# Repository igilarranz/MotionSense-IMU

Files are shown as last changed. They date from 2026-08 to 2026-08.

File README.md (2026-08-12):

# MotionSense IMU

MotionSense IMU is a custom 2-layer PCB built around the ST LSM6DSM 6-axis accelerometer and gyroscope.

The board takes 5 V from USB-C, regulates it to 3.3 V, and breaks out the IMU's I2C interface and interrupt signal through a 5-pin header.

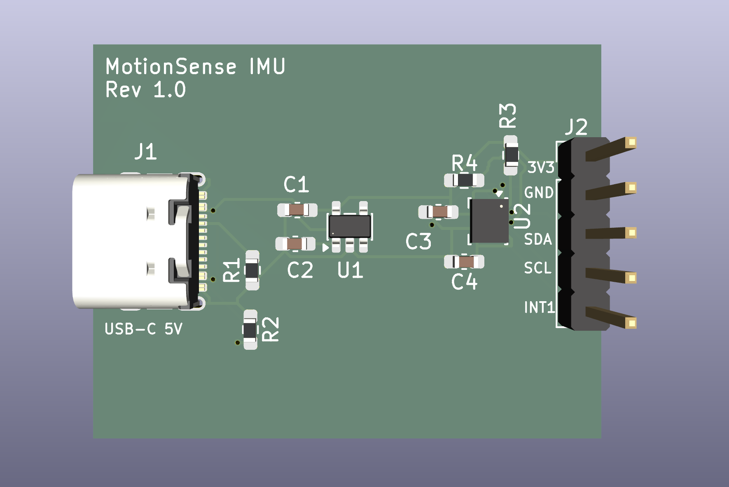
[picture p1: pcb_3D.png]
MotionSense IMU 3D Render


## Hardware

* LSM6DSM 6-axis accelerometer + gyroscope
* AP2112K-3.3 LDO regulator
* USB-C 5 V input
* 4.7 kΩ pull-up resistors on SDA and SCL
* Decoupling capacitors for the regulator and IMU
* 5-pin interface header
* 2-layer PCB
* Board size: approximately 35 mm × 27 mm

## Pinout

| Pin | Signal |
| --- | --- |
| 1 | 3V3 |
| 2 | GND |
| 3 | SDA |
| 4 | SCL |
| 5 | INT1 |

## Design

The schematic and PCB were designed in KiCad.

During routing, I experimented with Quilter and Freerouting before bringing the design back into KiCad for final cleanup and verification.

The final design passes KiCad DRC with:

* 0 violations
* 0 unconnected items

Gerber and drill files were generated and inspected before manufacturing.

## Schematic

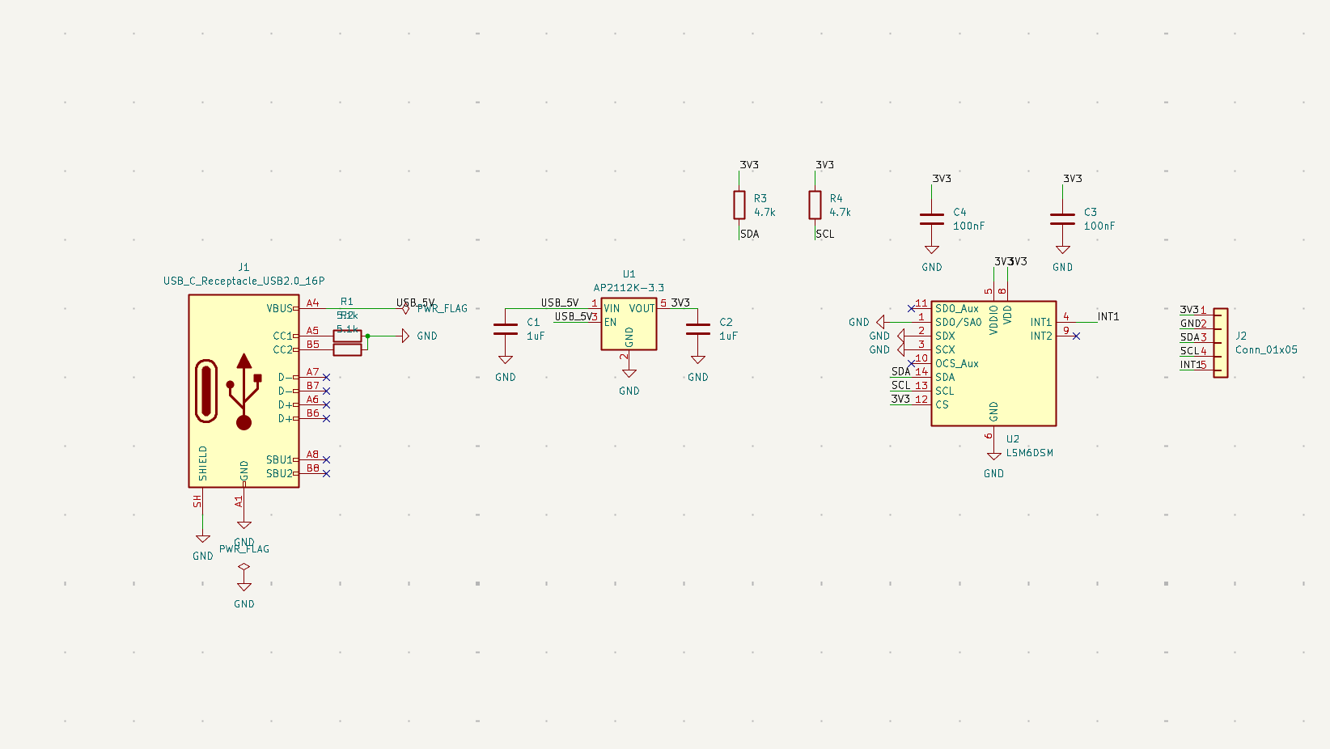
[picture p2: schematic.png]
MotionSense IMU Schematic


The schematic includes the USB-C power input, AP2112K 3.3 V regulator, LSM6DSM IMU, I2C pull-up resistors, decoupling capacitors, and J2 breakout header.

The editable KiCad schematic is available in `MotionSense_IMU.kicad_sch`.

## PCB Layout

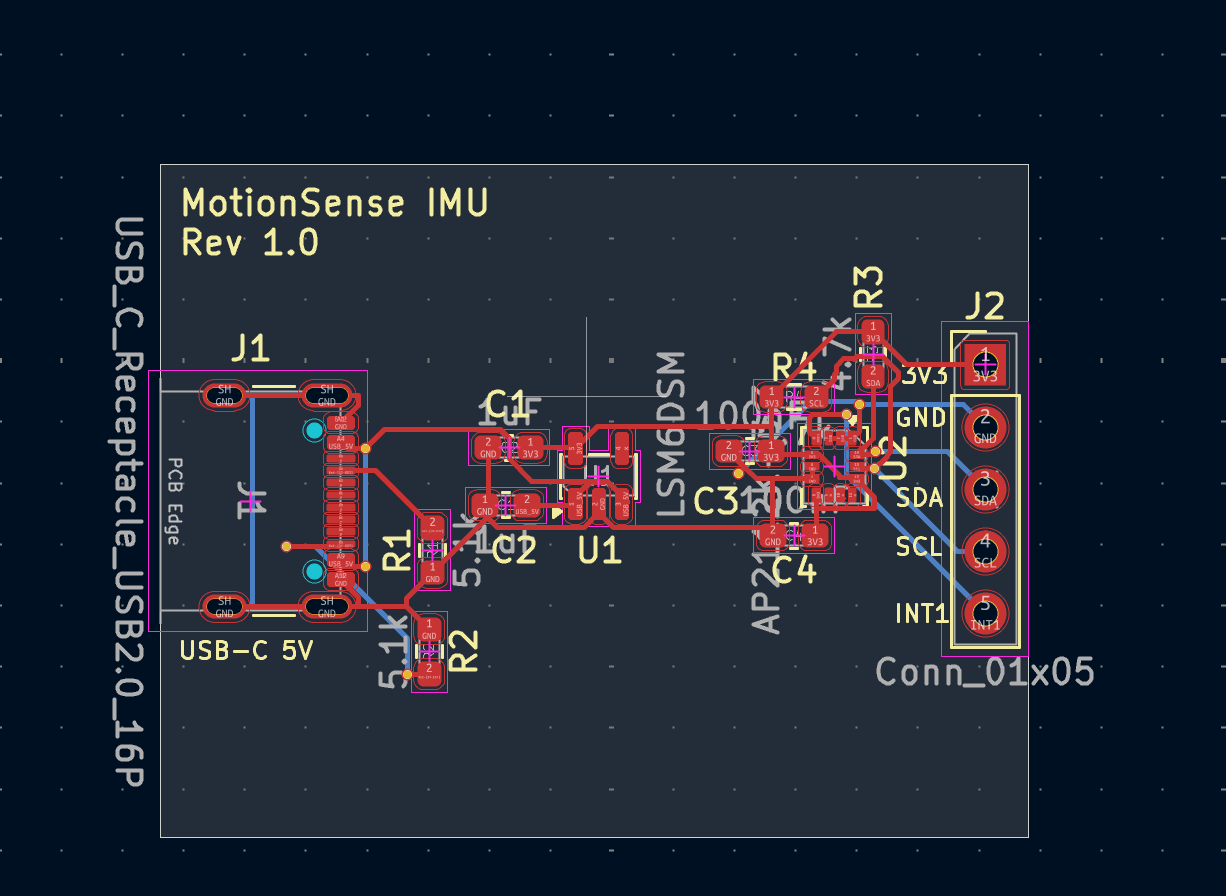
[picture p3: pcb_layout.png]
MotionSense IMU PCB Layout


The board is a 2-layer design with USB-C power input on one side and the I2C breakout header on the opposite side.

## Manufacturing

Rev 1 was submitted to JLCPCB for fabrication and assembly in August 2026.

Five PCBs were ordered, with two boards receiving component assembly.

The 1×5 J2 header is intentionally left unpopulated and will be soldered manually during bring-up.

## Files

* `MotionSense_IMU.kicad_pcb` — KiCad PCB layout
* `MotionSense_IMU.kicad_pro` — KiCad project
* `MotionSense_IMU.kicad_sch` — KiCad schematic
* `BOM.csv` — bill of materials
* `MotionSense_IMU_Rev1_Gerbers.zip` — Gerber and drill files
* `pcb_3D.png` — 3D board render
* `pcb_layout.png` — PCB layout image
* `schematic.png` — schematic image

## Fabrication Files

The Rev 1 Gerber and drill files used for manufacturing are included in the repository.

[Download Gerber + drill files](https://github.com/igilarranz/MotionSense-IMU/raw/refs/heads/main/MotionSense_IMU_Rev1_Gerbers.zip)

## Current Status

**Rev 1 has been ordered for fabrication and assembly.**

The PCB design and manufacturing files are complete. The next stage is hardware bring-up and firmware validation once the assembled boards arrive.

## Bring-Up Plan

1. Inspect the assembled board for soldering or placement issues.
2. Solder the J2 header.
3. Check for shorts between 3.3 V and GND.
4. Power the board through USB-C.
5. Verify the 5 V input and 3.3 V regulator output with a multimeter.
6. Connect an ESP32 to SDA, SCL, and GND.
7. Detect the LSM6DSM over I2C.
8. Read the `WHO_AM_I` register to confirm communication.
9. Read live accelerometer and gyroscope data.
10. Test the INT1 interrupt output.

## Next Steps

* Prepare ESP32 bring-up firmware
* Complete electrical testing
* Validate accelerometer and gyroscope measurements
* Test interrupt functionality
* Document test results
* Record any changes needed for Rev 2

## Project Goal

The goal of this project is to work through the complete PCB development process, from schematic capture and component selection through layout, manufacturing, assembly, and hardware validation.

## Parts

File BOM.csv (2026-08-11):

Reference | Value | Footprint
C1 | 1uF | Capacitor_SMD:C_0603_1608Metric_Pad1.08x0.95mm_HandSolder
C2 | 1uF | Capacitor_SMD:C_0603_1608Metric_Pad1.08x0.95mm_HandSolder
C3 | 100nF | Capacitor_SMD:C_0603_1608Metric_Pad1.08x0.95mm_HandSolder
C4 | 100nF | Capacitor_SMD:C_0603_1608Metric_Pad1.08x0.95mm_HandSolder
J1 | USB_C_Receptacle_USB2.0_16P | Connector_USB:USB_C_Receptacle_GCT_USB4105-xx-A_16P_TopMnt_Horizontal
J2 | Conn_01x05 | Connector_PinHeader_2.54mm:PinHeader_1x05_P2.54mm_Vertical
R1 | 5.1k | Resistor_SMD:R_0603_1608Metric_Pad0.98x0.95mm_HandSolder
R2 | 5.1k | Resistor_SMD:R_0603_1608Metric_Pad0.98x0.95mm_HandSolder
R3 | 4.7k | Resistor_SMD:R_0603_1608Metric_Pad0.98x0.95mm_HandSolder
R4 | 4.7k | Resistor_SMD:R_0603_1608Metric_Pad0.98x0.95mm_HandSolder
U1 | AP2112K-3.3 | Package_TO_SOT_SMD:SOT-23-5
U2 | LSM6DSM | Package_LGA:LGA-14_3x2.5mm_P0.5mm_LayoutBorder3x4y

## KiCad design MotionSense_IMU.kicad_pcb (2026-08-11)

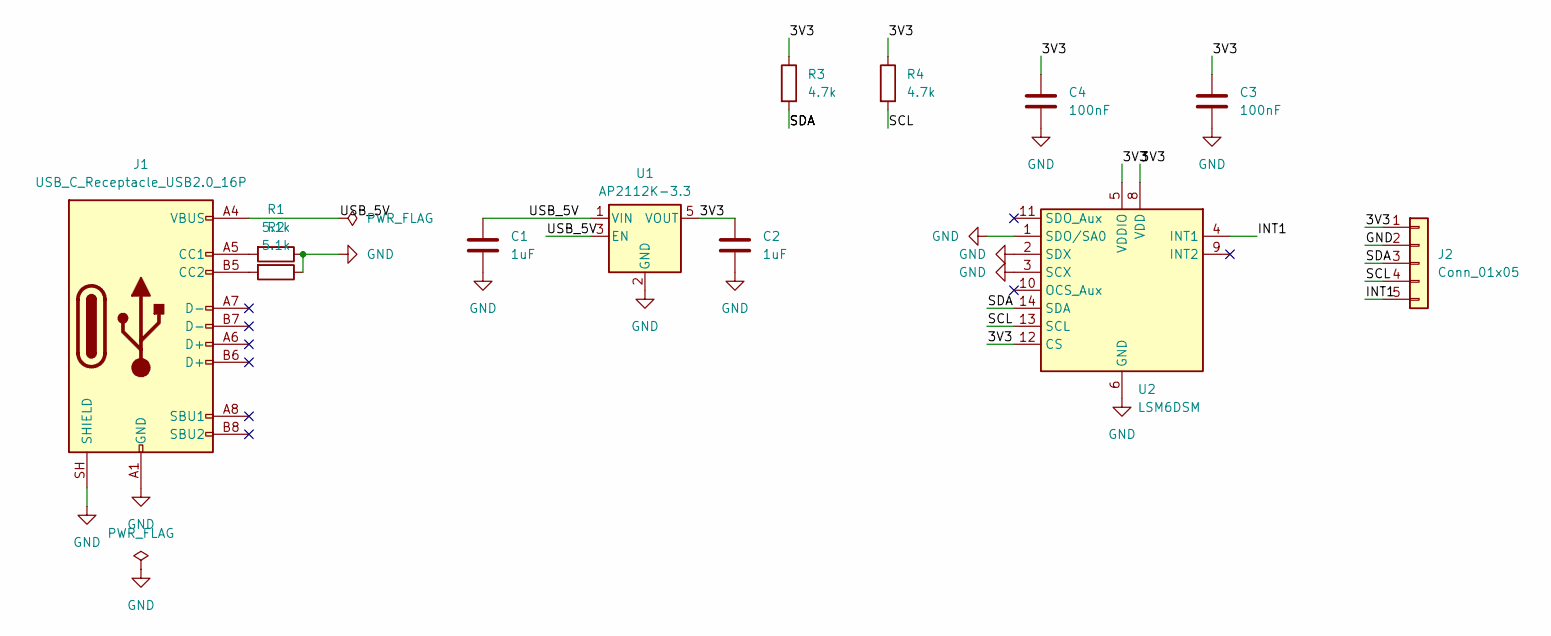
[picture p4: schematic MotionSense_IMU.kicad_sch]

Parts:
C1, C2: 1uF; C_0603_1608Metric_Pad1.08x0.95mm_HandSolder
C3, C4: 100nF; C_0603_1608Metric_Pad1.08x0.95mm_HandSolder
J1: USB_C_Receptacle_USB2.0_16P; USB_C_Receptacle_GCT_USB4105-xx-A_16P_TopMnt_Horizontal
J2: Conn_01x05; PinHeader_1x05_P2.54mm_Vertical
R1, R2: 5.1k; R_0603_1608Metric_Pad0.98x0.95mm_HandSolder
R3, R4: 4.7k; R_0603_1608Metric_Pad0.98x0.95mm_HandSolder
U1: AP2112K-3.3; SOT-23-5
U2: LSM6DSM; LGA-14_3x2.5mm_P0.5mm_LayoutBorder3x4y

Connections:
/3V3: C2.1, C3.1, C4.1, J2.1, R3.1, R4.1, U1.5 (VOUT), U2.5 (VDDIO), U2.8 (VDD), U2.12 (CS)
/INT1: J2.5, U2.4 (INT1)
/SCL: J2.4, R4.2, U2.13 (SCL)
/SDA: J2.3, R3.2, U2.14 (SDA)
/USB_5V: C1.2, J1.A4 (VBUS), J1.A9 (VBUS), J1.B4 (VBUS), J1.B9 (VBUS), U1.1 (VIN), U1.3 (EN)
GND: C1.1, C2.2, C3.2, C4.2, J1.A1 (GND), J1.A12 (GND), J1.B1 (GND), J1.B12 (GND), J1.SH (SHIELD), J2.2, R1.1, R2.1, U1.2 (GND), U2.1 (SDO/SA0), U2.2 (SDX), U2.3 (SCX), U2.6 (GND), U2.7 (GND)
unnamed: J1.A5 (CC1), R1.2
unnamed: J1.B5 (CC2), R2.2

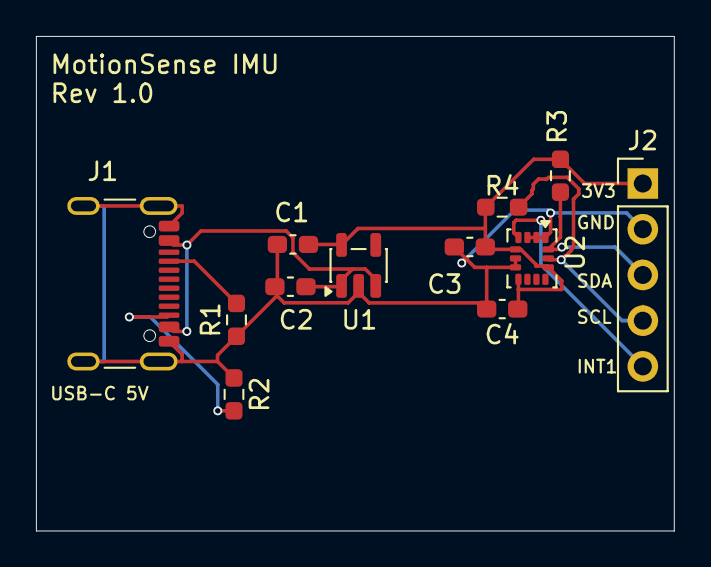
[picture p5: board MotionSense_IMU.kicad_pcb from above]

Board: 2 copper layers, 35.4 x 27.5 mm, 12 parts (0 on the bottom side), 8 nets.

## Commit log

2026-08-11 Initial MotionSense IMU hardware design
    [BOM.csv, MotionSense_IMU.kicad_pcb]
2026-08-11 Enhance README with design process and schematic details
    Updated the README to clarify design process and added schematic information.
2026-08-11 Update schematic reference and add preview image
2026-08-11 Revise schematic section in README
    Updated README to clarify schematic availability and removed redundant lines.
2026-08-12 Update README with schematic and fabrication details
    Added schematic and fabrication files sections to README.
2026-08-12 Update download link for Gerber and drill files
